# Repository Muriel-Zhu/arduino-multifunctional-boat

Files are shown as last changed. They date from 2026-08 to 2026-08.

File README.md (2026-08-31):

# Arduino Multifunctional Catamaran Prototype

这是一个基于 Arduino 的多功能双体船原型项目，项目报告整理自课程/实践设计成果，适合作为工程项目作品集展示。

> Personal learning and portfolio use only. Not for commercial use.

## Project Overview

本项目围绕小型遥控水面载具设计展开，目标是构建一套具备稳定航行、基础载荷搭载和水面交互能力的双体船原型。项目采用双船体结构提升横向稳定性，并结合 Arduino 控制、电机驱动、舵机机构和 3D 打印结构件完成系统集成。

## Key Features

- 双体船结构设计，提高水面航行稳定性和载荷承载能力。
- 使用 SolidWorks 完成船体、甲板、舱体和模块化结构建模。
- 基于 Arduino 搭建控制系统，实现推进与机械交互控制。
- 使用电机驱动模块、舵机和电源模块完成硬件集成。
- 通过 Tinkercad 等工具进行电路逻辑验证，降低硬件调试风险。
- 采用 3D 打印完成结构件制作，并进行装配与迭代优化。

## My Contributions

- 参与项目方案设计、结构建模与原型迭代。
- 使用 SolidWorks 完成核心结构件建模，并考虑 3D 打印装配可行性。
- 参与 Arduino 控制逻辑设计与硬件连接调试。
- 完成项目报告整理，梳理项目背景、开发流程、机械结构、电子架构和测试过程。

## Repository Structure

```text
.
├── README.md
├── .gitignore
├── docs
│   └── project-report.pdf
├── models
│   └── stl
│       ├── cabin.stl
│       ├── cage.stl
│       ├── frame.stl
│       ├── head.stl
│       ├── main-deck.stl
│       ├── marine-propeller-left.stl
│       ├── marine-propeller-right.stl
│       ├── pontoon-left.stl
│       └── pontoon-right.stl
└── src
    └── arduino
        └── sketch_apr20a
            └── sketch_apr20a.ino
```

## Project Report

完整项目报告见：

[docs/project-report.pdf](docs/project-report.pdf)

## Source Code

Arduino 控制代码见：

[src/arduino/sketch_apr20a/sketch_apr20a.ino](src/arduino/sketch_apr20a/sketch_apr20a.ino)

代码实现了双模式控制逻辑，包括航行模式、起重机模式、摇杆输入、舵机控制、电机驱动、超声波测距和 OLED 状态显示。

## 3D Printable Models

STL 模型文件位于：

[models/stl](models/stl)

这些文件用于展示双体船结构件和 3D 打印装配部件，包括船体浮筒、主甲板、舱体、框架、螺旋桨和保护结构等。

## Tech Stack

- Arduino
- SolidWorks
- 3D Printing
- Tinkercad
- Motor Driver
- Servo Control
- Embedded System Prototyping

## Notes

本仓库用于个人学习、作品集展示和求职材料补充，不包含商业交付内容，不用于商业用途。

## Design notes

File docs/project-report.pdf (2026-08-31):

# An Interactive Dual-Mode Catamaran Prototype: Project Nereus V3.1

# Content

An Interactive Dual-Mode Catamaran Prototype: Project Nereus V3.1

## 1. The Brief & Problem Statement

### 1.1 Context and Problem Definition

The primary objective of this project is to conceptualize, design, and develop a small-scale, remote-controlled marine vessel capable of assisting in local water quality monitoring, environmental surveying, or aquatic payload transport. Many existing hobbyist or entry-level

commercial remote-controlled (RC) boats utilize a standard monohull design, which inherently lacks the lateral stability required to carry delicate sensors or steady payloads. Furthermore, traditional RC boats are single-purpose (solely focused on propulsion), making them inadequate

for interactive tasks such as deploying and retrieving underwater equipment. Therefore, there is a tangible engineering need for a highly stable, multi-functional prototype that can navigate smoothly across water bodies while providing a reliable mechanical system for interacting with

### the aquatic environment. 1.2 Proposed Solution and Inspiration: "Project Nereus"

"Project Nereus" is an advanced, fully functional catamaran prototype engineered to demonstrate how a dual-hull structure can be seamlessly integrated with interactive mechanical systems. The core operational philosophy revolves around a "Dual-Mode System" managed by a custom-written operating system (Nereus OS), allowing the user to seamlessly switch between sailing and crane operations using a single dual-axis joystick. The conceptualization of the central payload deployment system was heavily inspired by the

video game Dave the Diver, specifically the mechanics of the underwater elevator escape pod. Drawing from this, we envisioned practical, real-world applications for a submersible elevator

cage. For instance, in marine harvesting, fishermen could place their caught nets directly into the submerged elevator. This ensures the fish remain in their natural ocean environment, significantly extending their survival time compared to being stored on a dry deck, while the

surrounding iron cage protects them from predators. Alternatively, scaled-up versions of this system could serve as temporary protective shark-cages for divers working in dangerous waters. While our current prototype cage is open at the top, it serves as a proof of concept that can easily

be enclosed or modified for actual industrial applications. As illustrated in Figure 1, this early conceptualization depicts the twin hulls and the central A-frame gantry lowering the Dave the Diver-inspired submersible cage.

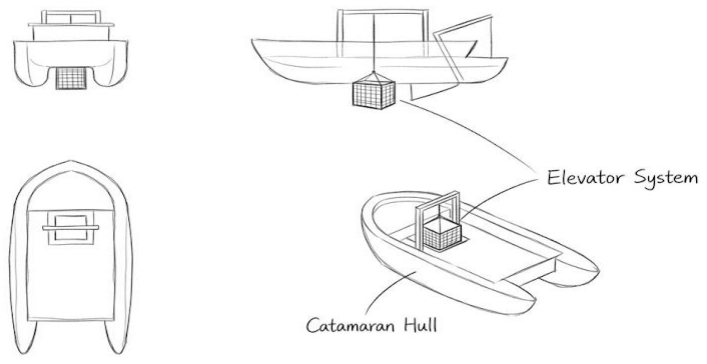
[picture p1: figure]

Figure 1: Early Minimalist Concept Sketch of the Project

## 2. Project Development Workflow & Iteration

The development of Project Nereus adhered to a rigorous, iterative prototyping pipeline, focusing heavily on overcoming technical bottlenecks, balancing mechanical robustness, and

ensuring electronic safety. The workflow commenced with conceptual 3D modeling in SolidWorks to define the vessel's

structural anatomy. Before any physical assembly, a critical Tinkercad simulation phase was conducted to validate the circuit logic and prevent hardware damage. Subsequently, hardware selection underwent a significant evolution. We upgraded from standard 9V batteries to a robust 7.4V Lithium-Polymer (Li-Po) battery, integrated an industrial-grade ZK-5AD motor driver, and refined our servo selection based on torque requirements. Following digital validation, the optimized parts were 3D printed. The final phase involved resolving complex software bugs and coding a non-blocking architecture to handle asynchronous screen rendering. This comprehensive evolutionary journey, from initial CAD drafting to final physical integration, is visually summarized in Figure 2, which highlights the iterative problem-solving approach taken throughout the project.

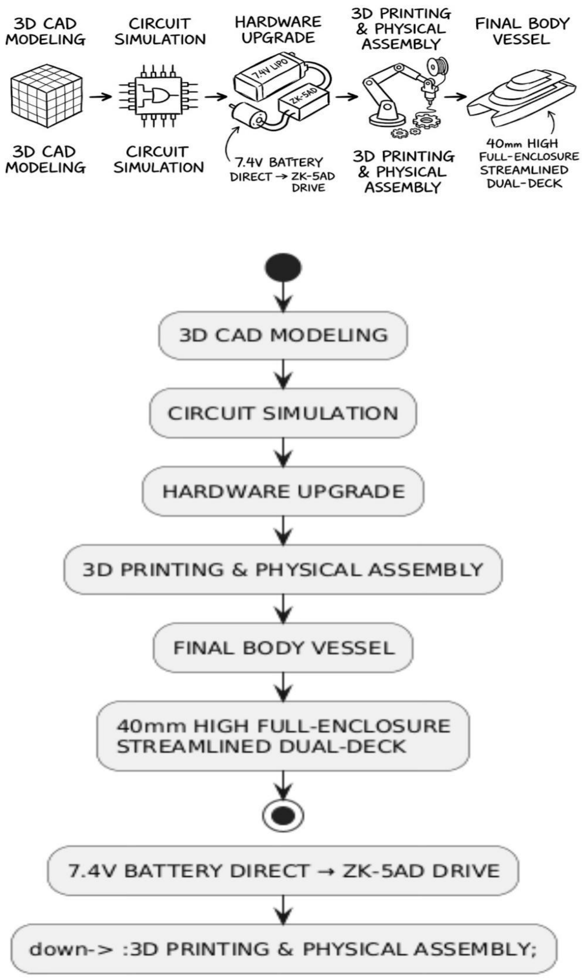
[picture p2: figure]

Figure 2: Flowchart of Project Development and Iteration

### 2.1 Project Schedule

The development of Project Nereus was executed over a four-week period. The following table 1 breaks down the key milestones and tasks completed during each phase:

Table 1：Course Project Schedule for Prototyping

Phase | Duration | Key Tasks and Milestones

Week 1 Concept & Initial

| Design | Defined the project scope inspired by the escape pod mechanics in Dave the Diver. Developed the first iteration of the vessel, initially conceptualized as a compact skiff rather than a

full-scale ship. Week 2 Functional Planning
| & Simulation | Finalized the dual-mode feature set. Conducted extensive circuit simulations in Tinkercad to validate the logic of mode-switching and I2C communication before physical

assembly. Week 3 Hardware Assembly
| & Troubleshooting | Focused on physical circuit construction. Significant time was invested in resolving persistent power configuration issues (USB crashes and common ground faults). Successfully
achieved full hardware-software synergy. Week 4 | Refinement, 3D
| Printing & Testing | Optimized the SolidWorks model into the final dual-deck streamlined hull. Printed 7 components and conducted final assembly. Executed field testing to ensure all functional

## requirements were met. 3. Mechanical Design and Aesthetic Engineering in

## SolidWorks

As the project evolved from a rudimentary skeleton to a professional marine research vessel, the mechanical design underwent a complete overhaul in SolidWorks to achieve both functional superiority and a refined "Tech-Style" aesthetic. 3.1 Hydrodynamic Pontoons and the Armored Deck

The foundation of the vessel utilizes two streamlined pontoons designed to minimize water resistance. In earlier design iterations, we attempted to protect the electronic components by engineering a 15mm high continuous coaming around a flat main deck. However, to achieve a superior industrial design and better space management, we completely overhauled the structure in the final version. We eliminated the basic coamings and introduced an innovative "dual-deck" architecture: a complete 40mm-high outer hull shell with a streamlined profile was constructed above the base plate, capped by a newly added upper deck. This design creates a spacious, enclosed internal cabin between the two decks, perfectly concealing all messy hardware and

wiring.Figure 3 demonstrates the precise fitment of these components that the front of this 40mm-high hull seamlessly integrates a slanted, streamlined bow splash guard. This major structural upgrade not only mitigates the "bow slamming" effect and significantly improves hydrodynamic performance, but also gives the vessel a continuous, sleek exterior that closely aligns with the classic aesthetic of a professional marine vessel.

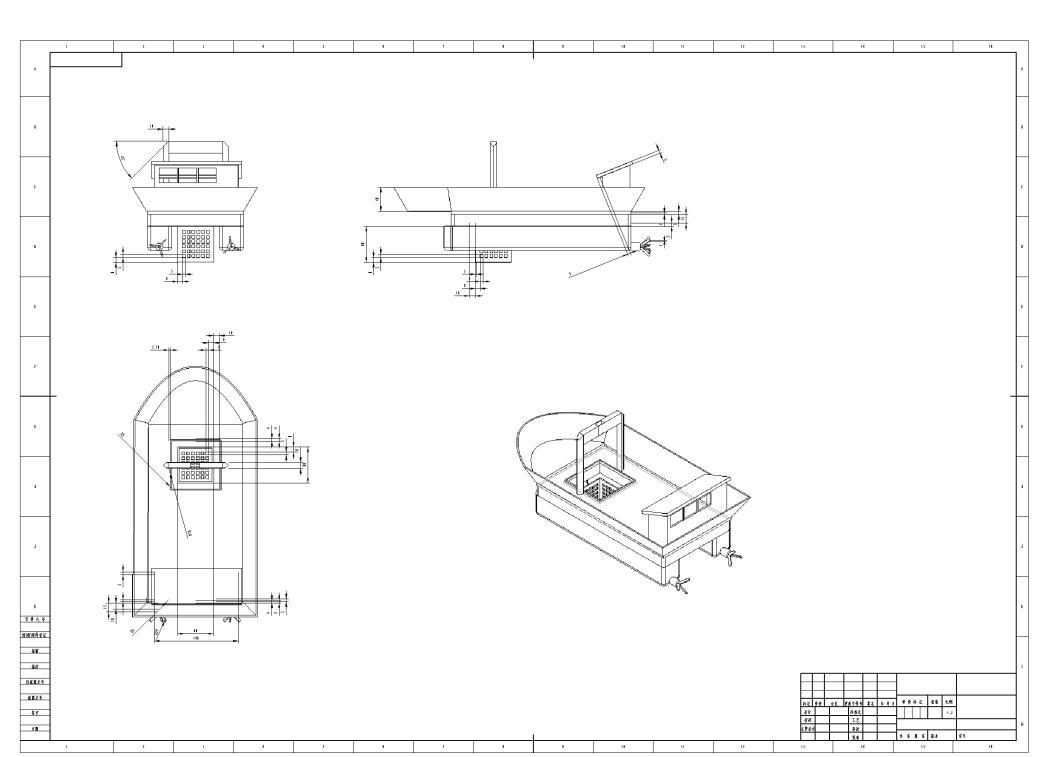
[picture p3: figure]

Figure 3: Screenshot of the Final SolidWorks Assembly

### 3.2 The Retro Cabin and A-Frame Gantry

To house the complex electronics, a hollow, single-slope retro cabin was designed. The cabin features a 3mm thin-wall construction and incorporates an overhanging hardtop canopy with observation windows to enhance the industrial aesthetic. Positioned directly above the moon pool is the A-Frame crane. This structure was designed with heavily chamfered edges to distribute mechanical stress. As captured in Figure 3 above, the SolidWorks assembly demonstrates the precise fitment of these components, particularly highlighting the distance mates applied to the submersible cage to simulate its vertical trajectory without intersecting the hulls.

### 3.3 Modular Component Design for 3D Printing

To facilitate rapid prototyping and ensure high-precision manufacturing, the mechanical structure of Project Nereus was engineered with a highly modular approach. Rather than attempting to print the vessel as a single complex monolithic block, the design was broken down into seven distinct, interchangeable CAD components. As illustrated in Figure 4, these individual custom-designed parts include: the flat upper deck

plate featuring the moon pool cutout, the 40mm streamlined outer hull shell with the integrated bow splash guard, the lower hydrodynamic pontoon base, the retro-style control cabin, the A-frame gantry structure, the submersible payload cage, and the custom 3-blade marine propeller. This modularity provided two significant engineering advantages. First, it allowed for rapid

individual component iteration during the design phase without the cost and time penalty of re-printing the entire boat. Second, it optimized the 3D printing process by allowing each part to be oriented flat on the print bed, drastically minimizing the need for wasteful breakaway support structures and ensuring a smoother surface finish for the final assembly.

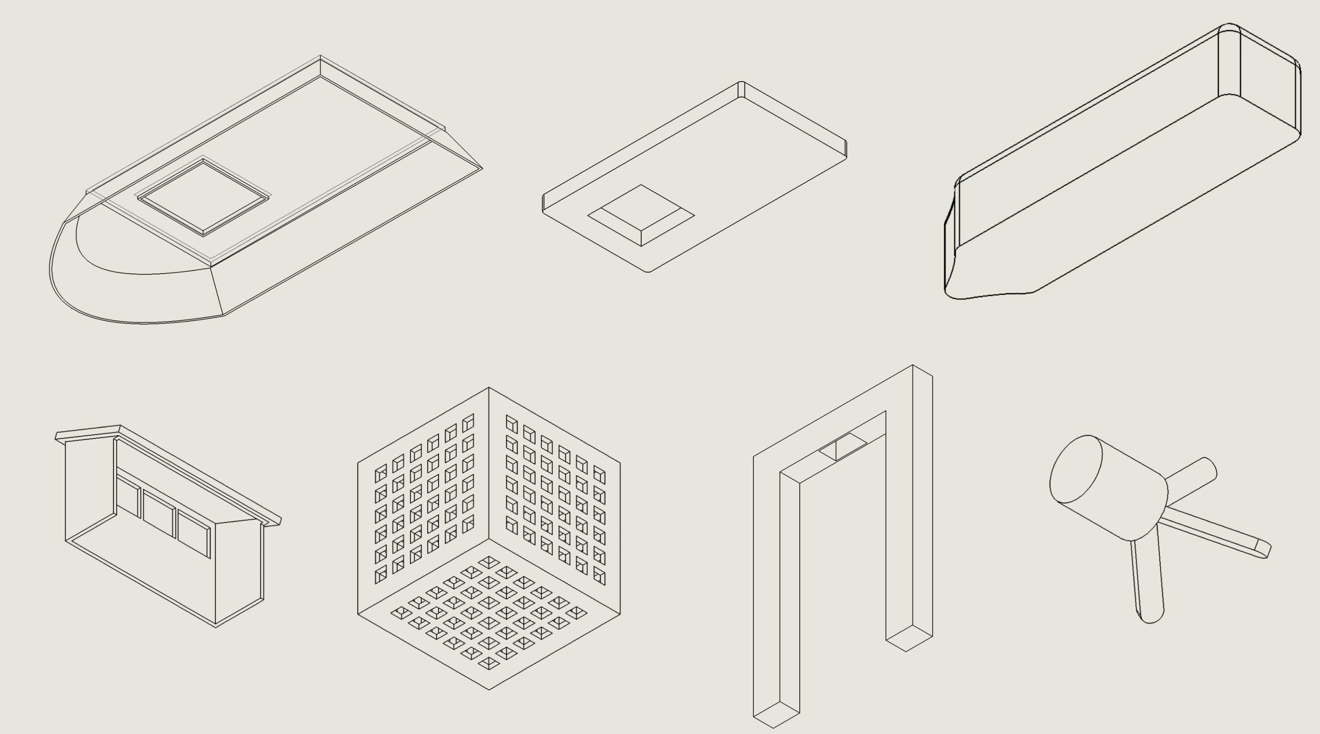
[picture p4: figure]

Figure 4: Isometric View of the 7 Custom 3D-Printed Modular Components

## 4. Hardware Selection and Electronic Architecture

Transitioning from a basic prototype to a high-performance vessel required addressing specific mechanical limitations through careful hardware selection. The current system is a carefully balanced network of high-voltage power components and low-voltage logic controllers. 4.1 Propulsion and the ZK-5AD Integration

The original 9V zinc-carbon battery was replaced with a high-discharge 7.4V Li-Po battery to power the main engine: the JGA25-370 geared DC motor. This motor provides exceptional torque at low RPMs. To control this motor, the ZK-5AD motor driver was selected. During the assembly, we faced a critical decision regarding the power input for the ZK-5AD. Initially considering the VT (Voltage Terminal) pin, we ultimately bypassed it and the adjacent GND pin entirely. Instead, we wired the 7.4V battery directly to the primary red power terminal block of the driver. This direct connection provided a much more stable and robust power delivery for the high-current demands of the JGA25-370 motor. 4.2 Differentiated Servo Configuration

A major hardware optimization involved differentiating the servo motors based on their specific mechanical tasks. Initially, we considered using two identical micro-servos. However, practical testing revealed that the steering mechanism required higher torque and specific angular constraints. Consequently, we integrated a heavy-duty MG996R servo exclusively for the steering rudder. The MG996R's built-in angle limitations and superior torque make it ideal for acting as a stable steering wheel. Conversely, the smaller SG90 micro-servo was retained for the A-Frame winch, as lowering and raising the lightweight cage required precision rather than raw power. The integration of this dual-servo system, alongside the OLED display and ultrasonic sensor, is explicitly mapped out in Figure 5 which details the power distribution and signal pathways.

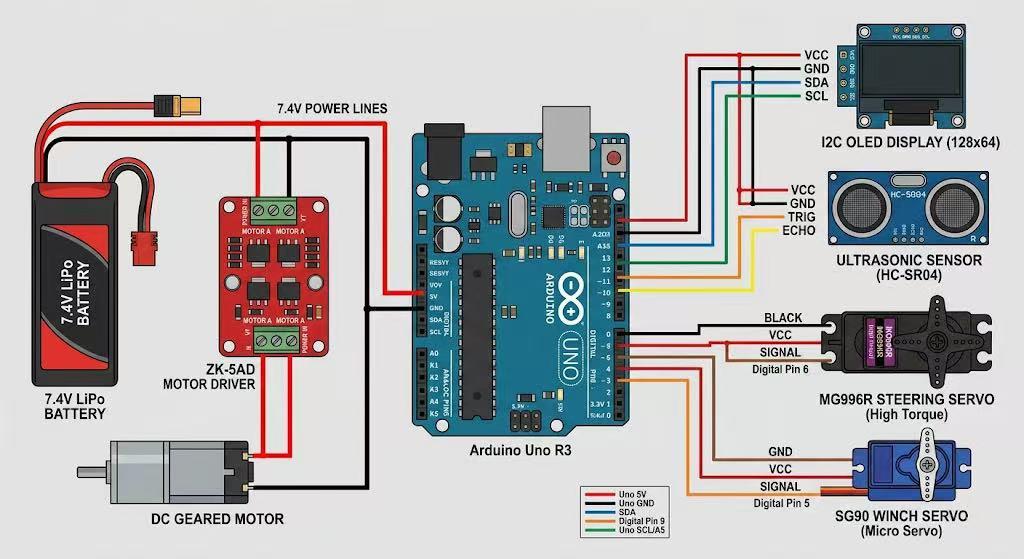
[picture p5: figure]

Figure 5: Topology Diagram of the Complete Circuit System

## 5. Overcoming Experimental Challenges: Troubleshooting and Power Strategy

The physical assembly and testing phase presented significant engineering challenges that required systematic troubleshooting. Highlighting these obstacles is crucial, as resolving them fundamentally shaped the final prototype. 5.1 The USB Overcurrent Crisis

The most critical hardware failure occurred when attempting to run the motors and servos simultaneously while connected to the computer. The system crashed, triggering an "Unrecognized USB Device" error on the host PC. We diagnosed this as a severe overcurrent protection trigger; the instantaneous current drawn by the JGA25-370 motor and the MG996R servo drastically exceeded the Arduino's 5V regulator limit and the USB interface's 500mA capacity, causing the computer's motherboard to physically sever the connection to protect itself. 5.2 Implementing "Water and Electricity Separation"

To resolve this, we engineered a strict "Power Isolation" strategy on the breadboard. The system was divided into a high-current zone and a low-current logic zone. As previously mentioned, the

7.4V battery was routed directly to the red power terminal of the ZK-5AD to handle the main propulsion. We then established a separate 5V rail to power the SG90 winch servo, the ultrasonic sensor, and the OLED display. The most vital step in this resolution was establishing a "Common Ground" by explicitly linking the ground of the 7.4V battery, the ZK-5AD driver, and the Arduino. Without this shared reference voltage, the PWM signals would remain unrecognizable. Figure 6 provides a close-up view of this implemented solution on the breadboard, clearly showing the power isolation and the crucial common ground connections that saved the microcontroller from frying.

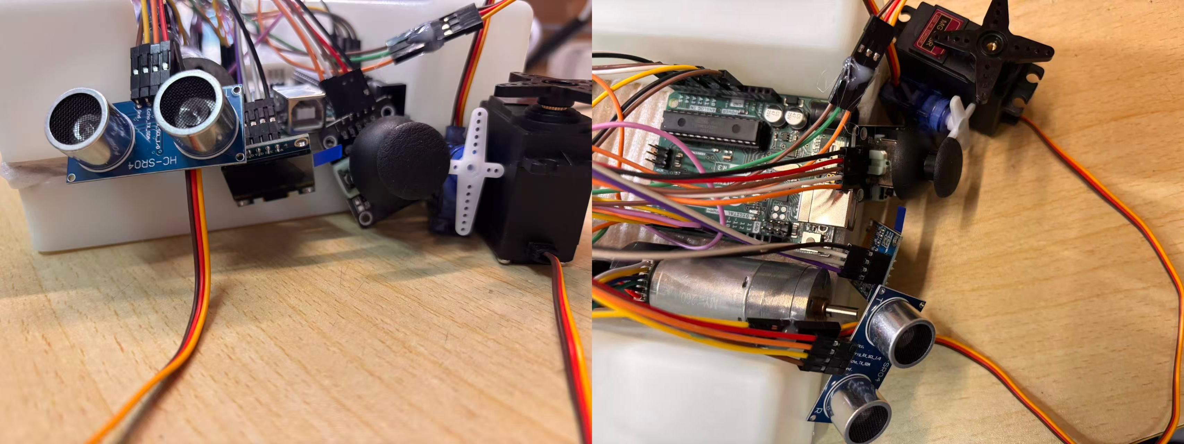
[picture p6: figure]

Figure 6: Physical Wiring on the Breadboard

## 6. Software Design and Tinkercad Simulation

The software architecture and pre-assembly simulations were pivotal in ensuring the prototype functioned smoothly without physically destroying components during trial and error. 6.1 Tinkercad Circuit Simulation and Logic Validation

Before wiring the physical 7.4V battery, we simulated the entire Nereus OS logic in Tinkercad. Since the platform lacks the specific ZK-5AD driver and SSD1306 OLED, we utilized an L293D

H-bridge and a 16x2 I2C LCD as equivalent components to test our PWM and I2C telemetry logic. During initial simulations, we encountered virtual "component explosion" errors because the simulated motor pulled current directly from the microcontroller. By correctly routing external power through the L293D—simulating our "Power Isolation" strategy—we eliminated these errors. As showcased in figure 7, the simulation successfully validated the dual-mode logic. The screenshots demonstrate the system's successful boot sequence and the seamless transition

between "SAIL" mode (main motor engaged at 100% power, telemetry active) and "CRANE" mode (main motor safely locked at 0% power, winch servo active), proving the software

architecture was completely sound before any physical wiring was attempted.

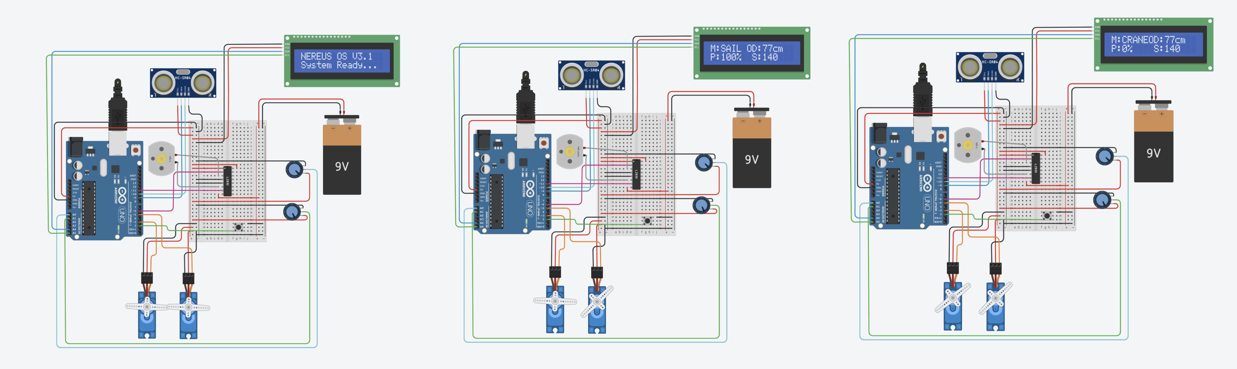
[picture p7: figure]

Figure 7: Screenshot of Tinkercad Simulation Running

### 6.2 Nereus OS V3.1 and the Screen Blocking Bug

The brain of the vessel is powered by a custom Arduino C++ program utilizing a robust State Machine. The analog joystick serves a dual purpose: providing X/Y values and acting as a digital pushbutton to toggle between "SAIL" and "CRANE" modes. We programmed a critical safety mechanism: when the mode switches, the code executes analogWrite(DRIVER_D0_PIN, 0); analogWrite(DRIVER_D1_PIN, 0);, instantly cutting the main engine. This prevents the boat from accelerating uncontrollably while the operator focuses on lowering the cage. A major software challenge emerged with the integration of the I2C OLED display. In an earlier

iteration, if the screen wires became loose due to vibrations, the display.begin() function failed, triggering a for(;;) infinite loop that completely froze the Arduino, rendering the boat dead in the

water. We rewrote the architecture in V3.1 to include a "Blind-Drive" fail-safe. If the screen fails to initialize, the code sets a boolean flag (hasScreen = false), bypasses the rendering functions, and forces the motor control loops to continue running. Furthermore, to prevent the

display.display() function from stuttering the servo movements, we implemented a non-blocking asynchronous timer using the millis() function, restricting screen updates to every 150 milliseconds. The intricate flow of this state machine and the fail-safe branches are logically mapped out in Figure 8.

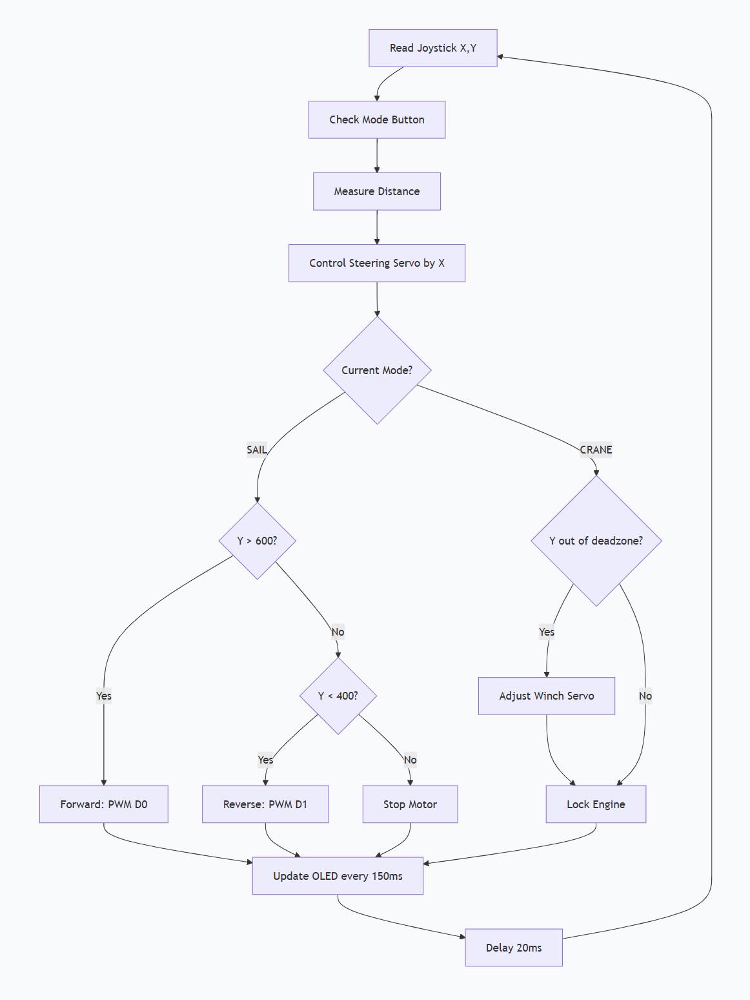
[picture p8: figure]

Figure 8: Program Logic Flowchart of Nereus OS v3.1

## 7. Interactive Aesthetics and Industrial Design

The final deliverable bridges the gap between mechanical engineering and industrial design. The structural elements are not merely functional; they represent a cohesive product identity. The integration of the OLED display transformed the remote control experience, providing a continuous stream of telemetry data including power output (PWR: %), steering angles, and radar proximity from the HC-SR04. The physical vessel, featuring the aggressive bow splash guard, the angled cabin hiding the

complex wiring, and the exposed A-frame crane, embodies a rugged, scientific aesthetic. It looks less like a hobbyist toy and more like a scaled-down industrial marine tool. The transformation from a bare-bones electronics testbed into a visually striking, mission-ready catamaran is showcased in Figure 9, displaying the vessel's polished exterior and operational stance.

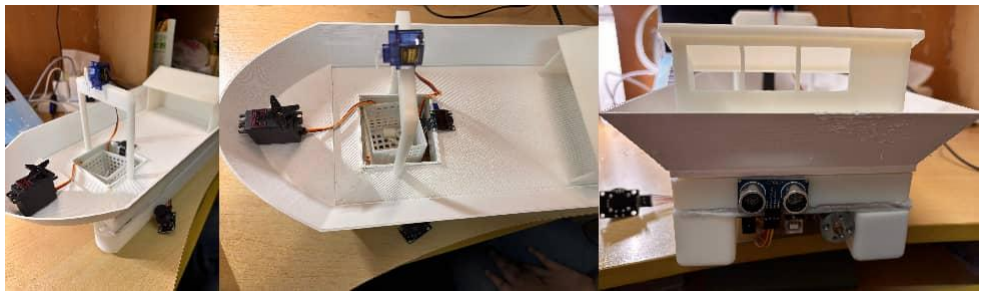
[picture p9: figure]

Figure 9: Real-world Photo

## 8. Bill of Materials (BOM)

The construction of the Project Nereus V3.1 prototype relied on a carefully curated set of electronic and mechanical components, each selected to address specific engineering requirements identified during our four-week iterative development process. Our hardware selection strategy prioritized a deliberate balance between performance, reliability, and resource efficiency, with targeted upgrades implemented to resolve initial power delivery and torque limitations. The finalized component list（Table 2）, presented in full on the following page, encapsulates all hardware iterations and optimizations made throughout the project, ensuring

seamless operation of both the dual-hull propulsion system and the precision payload deployment mechanism.

Table 2: Bill of Materials for Project Prototype

Designation | Quantity Component Description & Specification | | Total Cost
U1 | 1 | Arduino Uno R3 (Main Logic Controller) | 0
BAT1 | 1 | 7.4V 2S Li-Po Battery (High-Discharge Power Source) | 0
U2 | 1 | ZK-5AD High-Power Motor Driver Module | 0
M1 | 1 | JGA25-370 Geared DC Motor (Main Engine) | 0
SERVO_ST | 1 | MG996R High-Torque Servo (Steering Rudder Actuator) 0
SERVO_WI 1 | | SG90 Micro Servo (A-Frame Winch Actuator) | 0
DISP1 | 1 | 0.96-inch I2C SSD1306 OLED Display | 0
DIST1 | 1 | HC-SR04 Ultrasonic Distance Sensor | 0
JOY1 | 1 | Dual-Axis Analog Joystick with Pushbutton | 0
PROP | 1 | Custom 3D-Printed 3-Blade Marine Propeller | 0
3D Parts | 7 | Custom-designed Hull, Gantry, and Fittings | 314

## 9. Conclusion

Project Nereus V3.1 represents a comprehensive engineering journey, successfully transitioning from a conceptual idea inspired by Dave the Diver into a highly capable, dual-mode marine prototype. The project’s success is rooted in the rigorous troubleshooting of severe hardware and software issues. By analyzing and overcoming the USB overcurrent crashes through power isolation, and by reprogramming the software to bypass blocking loops using asynchronous millis() logic, we ensured the vessel's reliability. Furthermore, distinguishing our actuators—using the heavy-duty MG996R for steering and the precise SG90 for the payload elevator—maximized mechanical efficiency. The final vessel stands as a testament to iterative design, proving to be a stable, reliable, and aesthetically polished product ready to demonstrate interactive aquatic payload deployment in real-world environments. Reflecting on the entire development process, we have learned that rigorous hardware power

management is the absolute priority when integrating high-torque actuators with sensitive logic controllers. Although we successfully overcame significant setbacks, several key improvements would be implemented in future iterations to transition this prototype into a commercial-grade tool. First, we would prioritize the use of high-quality waterproof gaskets and marine-grade sealants to

fully hermeticize the dual-deck hull compartment. This would enable the vessel to move beyond its current "non-waterproof" demonstration phase and become a functional entity capable of long-term operations in natural, unpredictable water environments. Secondly, while the Dave the Diver-inspired open elevator cage performed reliably during testing, a future version would incorporate an automated top-hatch mechanism. This addition would ensure that payloads or aquatic samples are fully secured and protected from predators or environmental turbulence during transport. Ultimately, this project has not only significantly enhanced our hands-on engineering and

troubleshooting skills but also deepened our understanding of the delicate balance between sophisticated industrial aesthetic design and robust, hardcore engineering logic.

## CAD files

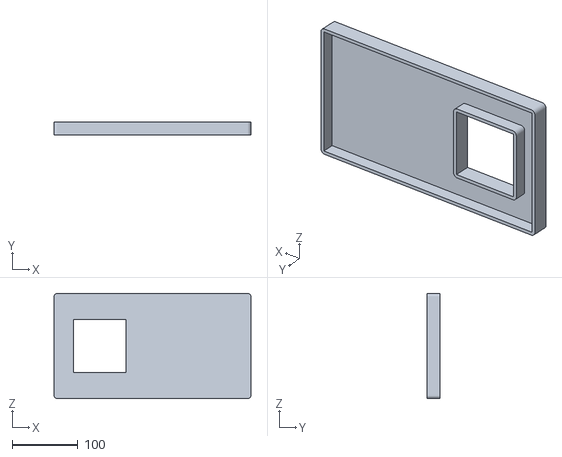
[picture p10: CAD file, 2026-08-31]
models/stl/main-deck.stl
300.0 x 20.0 x 160.0

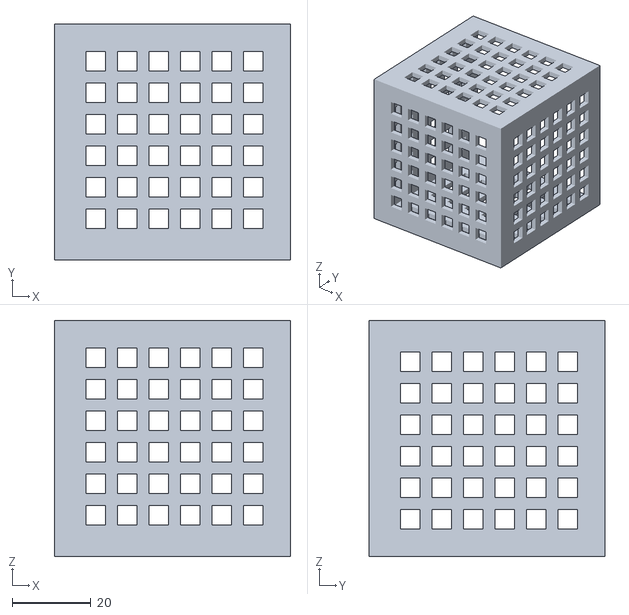
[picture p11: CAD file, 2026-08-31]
models/stl/cage.stl
60.0 x 60.0 x 60.0

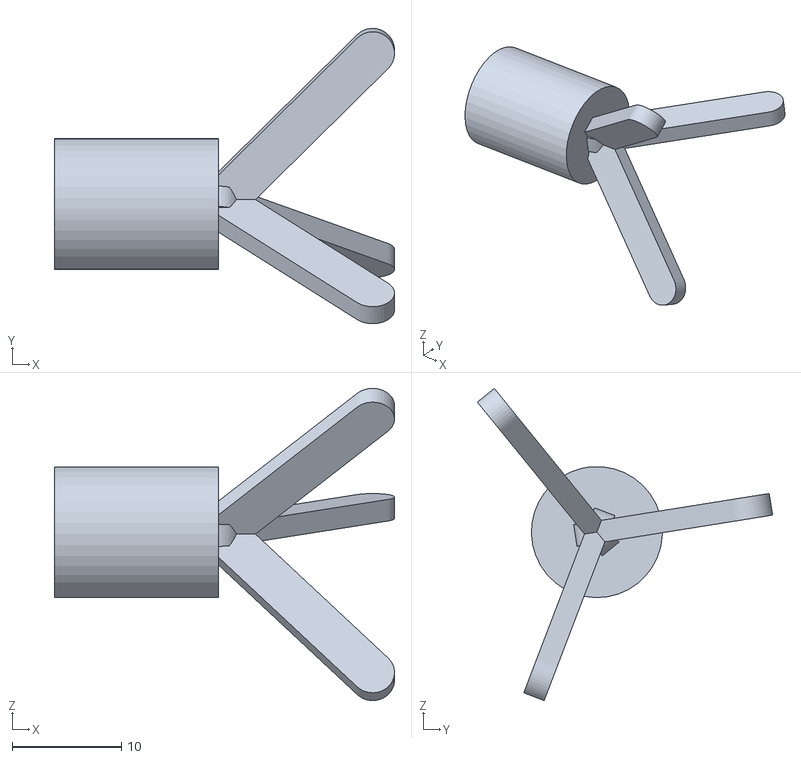
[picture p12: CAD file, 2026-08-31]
models/stl/marine-propeller-right.stl
31.1 x 27.0 x 28.6

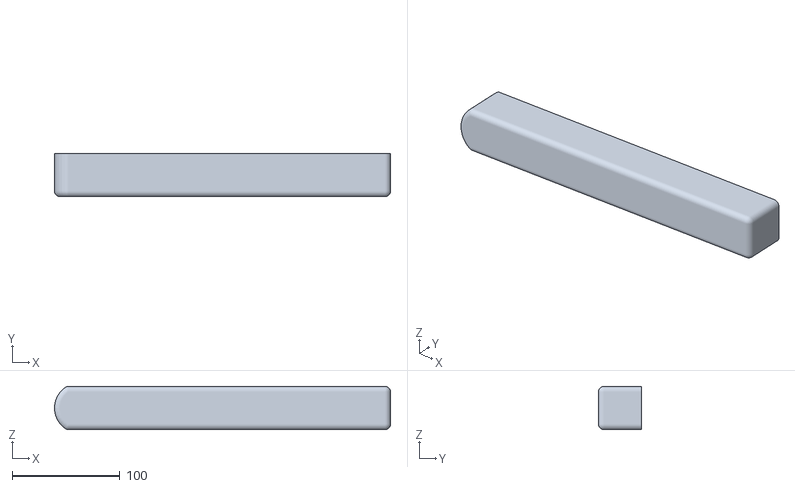
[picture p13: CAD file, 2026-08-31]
models/stl/pontoon-left.stl
311.3 x 40.0 x 40.0

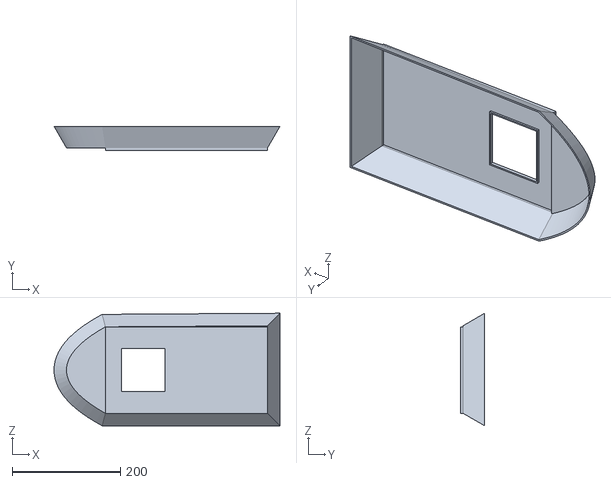
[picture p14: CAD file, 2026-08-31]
models/stl/head.stl
418.2 x 45.0 x 208.3

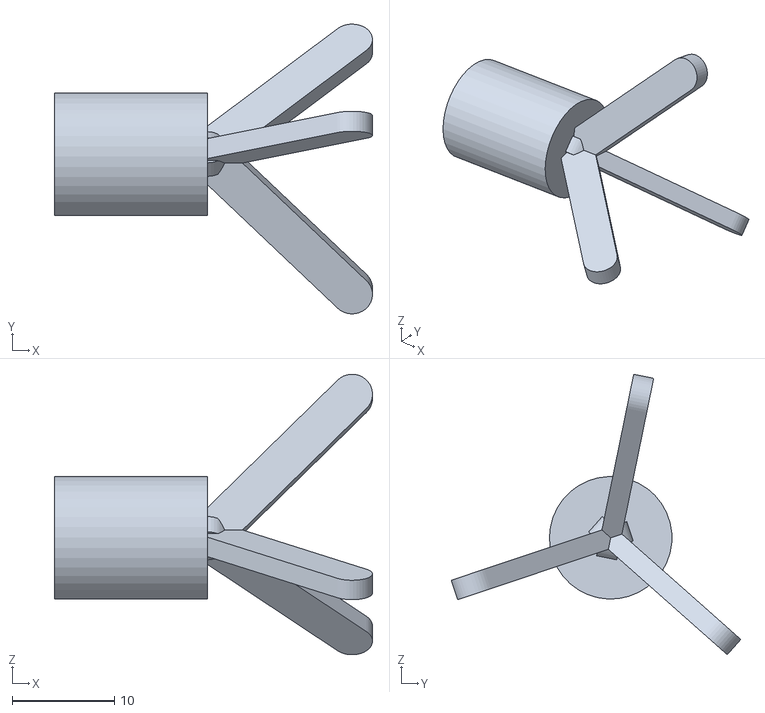
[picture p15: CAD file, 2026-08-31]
models/stl/marine-propeller-left.stl
31.1 x 28.4 x 27.5

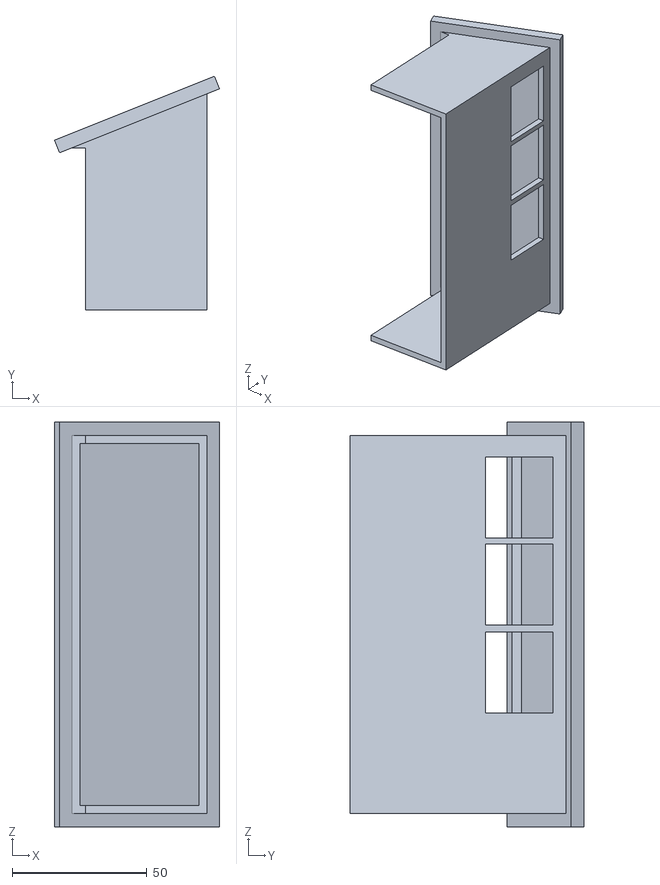
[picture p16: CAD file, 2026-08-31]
models/stl/cabin.stl
61.1 x 86.5 x 150.0

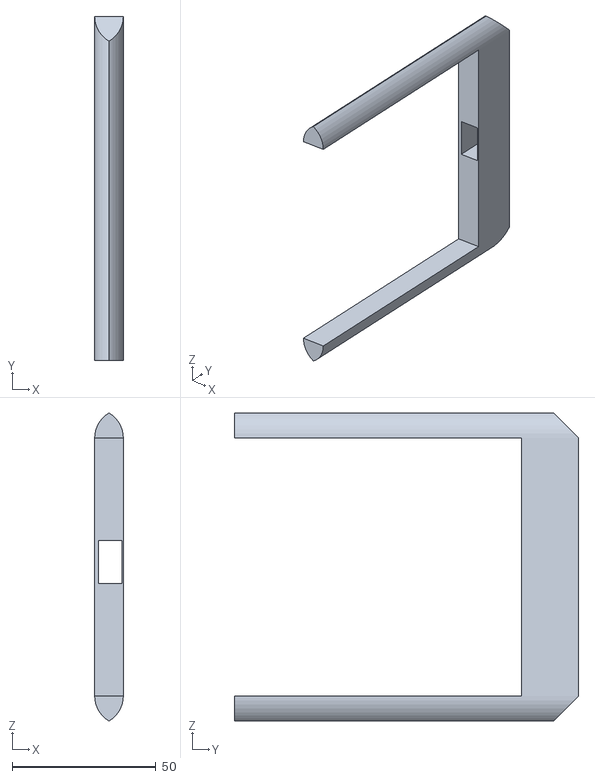
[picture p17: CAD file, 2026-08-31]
models/stl/frame.stl
10.0 x 120.0 x 107.3

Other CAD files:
models/stl/pontoon-right.stl

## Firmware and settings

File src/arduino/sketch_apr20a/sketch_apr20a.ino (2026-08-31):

#include <Servo.h>
#include <Wire.h>
#include <Adafruit_GFX.h>
#include <Adafruit_SSD1306.h>

// =======================================================
// PROJECT NEREUS - 科考船操作系统 v3.0 (带雷达显示屏)
// =======================================================

// --- 屏幕配置 ---
#define SCREEN_WIDTH 128 // OLED 显示宽度，以像素为单位
#define SCREEN_HEIGHT 64 // OLED 显示高度，以像素为单位
#define OLED_RESET    -1 // Reset pin # (or -1 if sharing Arduino reset pin)
Adafruit_SSD1306 display(SCREEN_WIDTH, SCREEN_HEIGHT, &Wire, OLED_RESET);

// --- 引脚分配 ---
const int JOY_Y_PIN = A0;   // 摇杆 Y 轴
const int JOY_X_PIN = A1;   // 摇杆 X 轴
const int BTN_MODE_PIN = 2; // 摇杆按键

const int SERVO_WINCH_PIN = 3;  // 起重机舵机
const int SERVO_STEER_PIN = 5;  // 转向舵机

// 根据你的驱动板更新了引脚名称 (D0/D1 对应 6和11)
const int DRIVER_D0_PIN = 6;    // ZK-5AD D0 (前进)
const int DRIVER_D1_PIN = 11;   // ZK-5AD D1 (后退)

const int TRIG_PIN = 9;         // HC-SR04 超声波 Trig
const int ECHO_PIN = 10;        // HC-SR04 超声波 Echo

// --- 核心控制对象 ---
Servo winchServo;
Servo steerServo;

enum SystemMode { SAIL, CRANE };
SystemMode currentMode = SAIL;

int winchPos = 90; 
int steerPos = 90; 
unsigned long lastButtonPress = 0;

// 屏幕刷新计时器 (防止屏幕刷新拖慢舵机)
unsigned long lastDisplayUpdate = 0;
float currentDistance = 0.0;
int currentEngineSpeed = 0;
String engineStatus = "STOP";

void setup() {
  Serial.begin(9600); 
  
  // 初始化引脚
  pinMode(BTN_MODE_PIN, INPUT_PULLUP); 
  pinMode(DRIVER_D0_PIN, OUTPUT);
  pinMode(DRIVER_D1_PIN, OUTPUT);
  pinMode(TRIG_PIN, OUTPUT);
  pinMode(ECHO_PIN, INPUT);

  // 初始化舵机
  winchServo.attach(SERVO_WINCH_PIN);
  steerServo.attach(SERVO_STEER_PIN);
  winchServo.write(winchPos);
  steerServo.write(steerPos);

  // 确保电机静止
  analogWrite(DRIVER_D0_PIN, 0);
  analogWrite(DRIVER_D1_PIN, 0);

  // 初始化 OLED 屏幕
  if(!display.begin(SSD1306_SWITCHCAPVCC, 0x3C)) { // 一般地址为 0x3C
    Serial.println(F("SSD1306 allocation failed"));
    for(;;); // 屏幕初始化失败则卡住
  }
  
  display.clearDisplay();
  display.setTextSize(2);
  display.setTextColor(SSD1306_WHITE);
  display.setCursor(10, 20);
  display.println(F("NEREUS OS"));
  display.setTextSize(1);
  display.setCursor(10, 45);
  display.println(F("Booting..."));
  display.display();
  delay(1500); // 显示开机画面 1.5 秒
}

void loop() {
  // 1. 读取摇杆数据
  int joyX = analogRead(JOY_X_PIN); 
  int joyY = analogRead(JOY_Y_PIN); 

  // 2. 模式切换逻辑
  if (digitalRead(BTN_MODE_PIN) == LOW) {
    if (millis() - lastButtonPress > 500) { 
      currentMode = (currentMode == SAIL) ? CRANE : SAIL;
      
      // 切换模式安全急停
      analogWrite(DRIVER_D0_PIN, 0);
      analogWrite(DRIVER_D1_PIN, 0);
      engineStatus = "STOP";
      
      lastButtonPress = millis();
    }
  }

  // 3. 超声波探测 (只负责测距，不打印串口，避免卡顿)
  digitalWrite(TRIG_PIN, LOW);
  delayMicroseconds(2);
  digitalWrite(TRIG_PIN, HIGH);
  delayMicroseconds(10);
  digitalWrite(TRIG_PIN, LOW);
  long duration = pulseIn(ECHO_PIN, HIGH, 30000); 
  currentDistance = duration * 0.034 / 2;

  // 4. 转向系统
  if (joyX > 600) steerPos += 2;
  else if (joyX < 400) steerPos -= 2;
  steerPos = constrain(steerPos, 40, 140); 
  steerServo.write(steerPos);

  // 5. 动力核心分流
  if (currentMode == SAIL) {
    if (joyY > 600) {
      currentEngineSpeed = map(joyY, 600, 1023, 0, 255);
      analogWrite(DRIVER_D0_PIN, currentEngineSpeed);
      analogWrite(DRIVER_D1_PIN, 0);
      engineStatus = "FWD>>"; // 前进
    } else if (joyY < 400) {
      currentEngineSpeed = map(joyY, 400, 0, 0, 255);
      analogWrite(DRIVER_D0_PIN, 0);
      analogWrite(DRIVER_D1_PIN, currentEngineSpeed);
      engineStatus = "<<REV"; // 倒车
    } else {
      analogWrite(DRIVER_D0_PIN, 0);
      analogWrite(DRIVER_D1_PIN, 0);
      engineStatus = "STOP";
    }
  } else {
    // 起重机模式
    if (joyY > 600) winchPos += 2; 
    else if (joyY < 400) winchPos -= 2; 
    winchPos = constrain(winchPos, 0, 180);
    winchServo.write(winchPos);
    engineStatus = "LOCKED"; // 主引擎锁死
  }

  // 6. 异步刷新 OLED 屏幕 (每 150ms 刷新一次，保证舵机丝滑不卡)
  if (millis() - lastDisplayUpdate > 150) {
    updateScreen();
    lastDisplayUpdate = millis();
  }

  delay(20); 
}

// 屏幕绘制函数
void updateScreen() {
  display.clearDisplay();
  
  // 第一行：当前模式
  display.setTextSize(1);
  display.setCursor(0, 0);
  display.print(F("MODE: "));
  display.setTextSize(2);
  display.setCursor(35, 0);
  if (currentMode == SAIL) {
    display.print(F("SAIL"));
  } else {
    display.print(F("CRANE"));
  }
  
  // 画一条分割线
  display.drawLine(0, 18, 128, 18, SSD1306_WHITE);

  // 第二行：雷达距离
  display.setTextSize(1);
  display.setCursor(0, 25);
  display.print(F("RADAR: "));
  if (currentDistance == 0 || currentDistance > 200) {
    display.print(F("CLEAR"));
  } else {
    display.print(currentDistance, 1);
    display.print(F(" cm"));
    // 危险警告框
    if (currentDistance < 15.0) {
      display.fillRect(90, 23, 38, 11, SSD1306_WHITE);
      display.setTextColor(SSD1306_BLACK);
      display.setCursor(92, 25);
      display.print(F("WARN!"));
      display.setTextColor(SSD1306_WHITE); // 恢复白色字
    }
  }

  // 第三行：主引擎状态
  display.setCursor(0, 40);
  display.print(F("ENG: "));
  display.print(engineStatus);
  if (currentMode == SAIL && engineStatus != "STOP") {
    display.print(F(" PWR:"));
    int pwrPercent = map(currentEngineSpeed, 0, 255, 0, 100);
    display.print(pwrPercent);
    display.print(F("%"));
  }

  // 第四行：舵机状态
  display.setCursor(0, 55);
  display.print(F("STR:"));
  display.print(steerPos);
  display.print(F("   WINCH:"));
  display.print(winchPos);

  display.display();
}
